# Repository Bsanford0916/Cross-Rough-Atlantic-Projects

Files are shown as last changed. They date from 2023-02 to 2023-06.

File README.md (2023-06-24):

**Welcome**

Hi there and welcome! Thanks alot for checking out Mjölnir - We've been so excited to share this with you, that we simply could'nt wait any longer. This blaster is for the community, by the community. 

This is the finished blaster after about 8 months of work from alot of cool people, but we are hobby-nerf folk, not professionals (Try it out at your own risk).

This is a personal blaster for you and we want you to mod it. There is however a few legal things; The code is a mix of Airzone's free code. This means you are not allowed to sell it. The same goes for the design, which is mainly because we dont want to get kicked off github later on.. 😛 

But you are free to use it as you please to mod etc. You can print all the blasters you want for friends and family for the cost of filament and hugs.

if you have any questions, feel free to reach out to us via discord (https://discord.gg/Edy7qAxdAY) or facebook. 

Kind regards,

Ben, Thor and the rest of the C.R.A.P team

(Cross Rough Atlantic Projects)

**Licensing and Production**
Cross-Rough-Atlantic-Projects are all licensed under CC-BY-SA-NC https://creativecommons.org/licenses/by-nc-sa/4.0/

Shameless donation link:
https://www.buymeacoffee.com/projectmjolnir

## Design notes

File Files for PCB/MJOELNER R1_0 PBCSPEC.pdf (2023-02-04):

PCB SPECIFICATION DOCUMENT

PROJECT NAME / # | MJOELNER
PROJECT AUTHOR | TLH
PCB REVISION | 1.0
PCB BASE MATERIAL | FR-4, IPC-4101/21, Tg>110
PCB STACKUP | 4 layer: 4001: Standard 1.6mm 1oz (FR4)
PCB THICKNESS | 1.6 mm
PCB SIZE (mmXmm) | 66 X 30
Number of copper layers | 4
Copper thickness outer layers µm | 35
Copper thickness inner layers µm | 35
Surface finish | ENIG Gold (Ni/Au)
Solder mask | GREEN
Notation | WHITE

Gerber File extensions

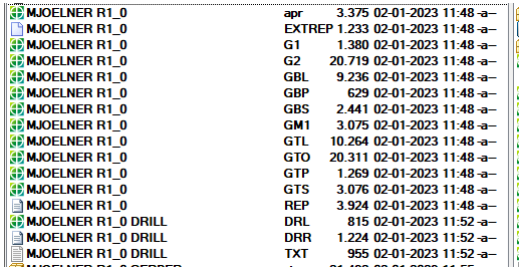
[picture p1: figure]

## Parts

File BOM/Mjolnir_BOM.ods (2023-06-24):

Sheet: Mjolnir
Mjölnir Base Components
Project files on Github | https://github.com/Bsanford0916/Cross-Rough-Atlantic-Projects
Item | Quantity | Link | Notes
Hardware
M3 screw 6mm (Button Head) | 8 | https://a.co/d/f6d6F2C
M3 screw 8mm (Button Head) | 2 | See options for sizes in above link.
M3 screw 10mm (Button Head) | 7 | See options for sizes in above link.
M2 screw 16mm (Button Head) | 4 | https://a.co/d/7gcIDZh
M2 screw 18mm (Button Head) | 1 | See options for sizes in above link.
Heat Insert (M3x3mm Lengthx5mm OD) | 17 | Https://a.co/d/2s1DLBN
Ballpen spring (mag release) | 1
5mmx2mm Magnet (Battery Lid) | 2
Electronics
Iflight Xing2 1404 4600kV | 2 | Https://a.co/d/bhoQbUt
Blheli_32 35A ESC (20A will work) | 1
Arduino Nano (Atmega328) | 1
Solenoid OOD Neutron | 1 | https://outofdarts.com/products/high-rate-of-fire-compact-solenoid
Rotary Encoder (with push switch) | 1 |  | KY-040 Without board, also in PCB BOM
0.96in OLED I2C (SSD 1306) | 1 | https://a.co/d/a85g2Zs
MicroSwitch 10A | 1 | https://outofdarts.com/products/10a-microswitch-cherry-db2-with-lever | Also in PCB BOM
MicroSwitch 1A | 1 | https://outofdarts.com/products/micro-switch-1a-for-mosfet-builds
Lipo 3s | 1 |  | 650mAh 75c 3s confirmed
22AWG wire | N/A
28AWG Wire | N/A
XT30 set | 1

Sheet: Mjolnir XL
Mjölnir XL Base Components
Project files on Github | https://github.com/Bsanford0916/Cross-Rough-Atlantic-Projects
Item | Quantity | Link | Notes
Hardware
Electronics

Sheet: Mjolnir Carbine
Mjölnir Carbine Base Components
Project files on Github | https://github.com/Bsanford0916/Cross-Rough-Atlantic-Projects
Item | Quantity | Link | Notes
Hardware
Electronics

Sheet: PCB Electronics
Mjölnir PCB Electronics Components
Project files on Github | https://github.com/Bsanford0916/Cross-Rough-Atlantic-Projects
Item | Quantity | Link | Notes
PCB
Capacitor 25v, 47uF | 1 | https://www.mouser.com/ProjectManager/ProjectDetail.aspx?AccessID=42ba671b8e | All in one Order BOM
Ceramic Capacitor 16v, 10uF | 2 |  | MLCC X7R 1206
Zener Diode 5v1 (BZT52C5V1) | 1 |  | SOD-123
Diode (VS-10MQ040-M3/5AT) | 2 |  | Do-214AC (SMA)
Voltage Regulator (UA7805M05CDCY) | 1 |  | SOT223-S
P-channel Mosfet (IPD30N10S3L34ATMA1) | 1 |  | Dpak (TO-252)
47k 1% 0.125W Resistor | 1 |  | R0805
10k 1% 0.125W Resistor | 2 |  | R0805
1k 1% 0.125W Resistor | 1 |  | R0805
2pin Header, 100mil | 2
4pin Header, 100mil | 1
5pin Header, 100mil | 1

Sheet: Alternate Parts
Mjölnir Alternate Components
Project files on Github | https://github.com/Bsanford0916/Cross-Rough-Atlantic-Projects
Item | Quantity | Link | Notes
Micro Dual BEC Board, 7-21V to 5V/12V ADJ | 1 | Https://a.co/d/8TOD3Te | Alternate Component
Isolated Mosfet Relay Board 30V 161A | 1 | Https://a.co/d/1EoDc6Q | LR7843
Solenoid 12V 2.5A (FJ-Z05 or OOD Neutron) | 1 | FJ-Z05 Solenoid Link https://a.co/d/eShqyR8 | Link says JF-Z05, but is the FJ-Z05 solenoid

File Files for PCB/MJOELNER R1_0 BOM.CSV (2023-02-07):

Comment | Pattern | Quantity | Components
NOT MOUNTED | RAD �7 X 2.54 | 1 | C3 | 47 �F/ 25 V
10k 1% .125w 0805 | R0805 | 1 | R2 | Resistor
10k 1% 0.125W 0805 | R0805 | 1 | R4 | Resistor
1k 1% 0.125W 0805 | R0805 | 1 | R3 | Resistor
47k 1% 0.125W 0805 | R0805 | 1 | R1 | Resistor
NOT MOUNTED |  | 1 | IC1 | ARDUINO NANO CONTROLLER
BZT52C5V1 | SOD-123 | 1 | D3 | ZENER 5V1
NOT MOUNTED | TLH ESC | 2 | J1, J4 | ESC CONNECT
NOT MOUNTED | FIDUCIAL | 2 | FIDUCIAL 1, FIDUCIAL 2
NOT MOUNTED | TLH 2PIN 100MIL | 2 | J8, J9 | Header 2 PIN 100 MIL
NOT MOUNTED | TLH 2PIN 100MIL | 1 | J5 | Header, 2-PIN 100 MIL
NOT MOUNTED | TLH 4PIN 100MIL | 1 | J7 | Header, 4-PIN 100 MIL
NOT MOUNTED | TLH 5PIN 100MIL | 1 | J6 | Header, 5-PIN 100 MIL
IPD30N10S3L34ATMA1 | TLH DPAK | 1 | Q1 | RS 671-0788
MLCC X7R 1206 | C1206 | 2 | C1, C2 | RS# 802-9961
NOT MOUNTED | TLH PWR IN | 1 | J2 | PWR IN HEADER
NOT MOUNTED | TLH PWR IN | 1 | J3 | SOLENOID CONNECT
UA7805M05CDCY | SOT223-S | 1 | IC2 | TEXAS
VS-10MQ040-M3/5AT | SMA | 2 | D1, D2 | Default Diode

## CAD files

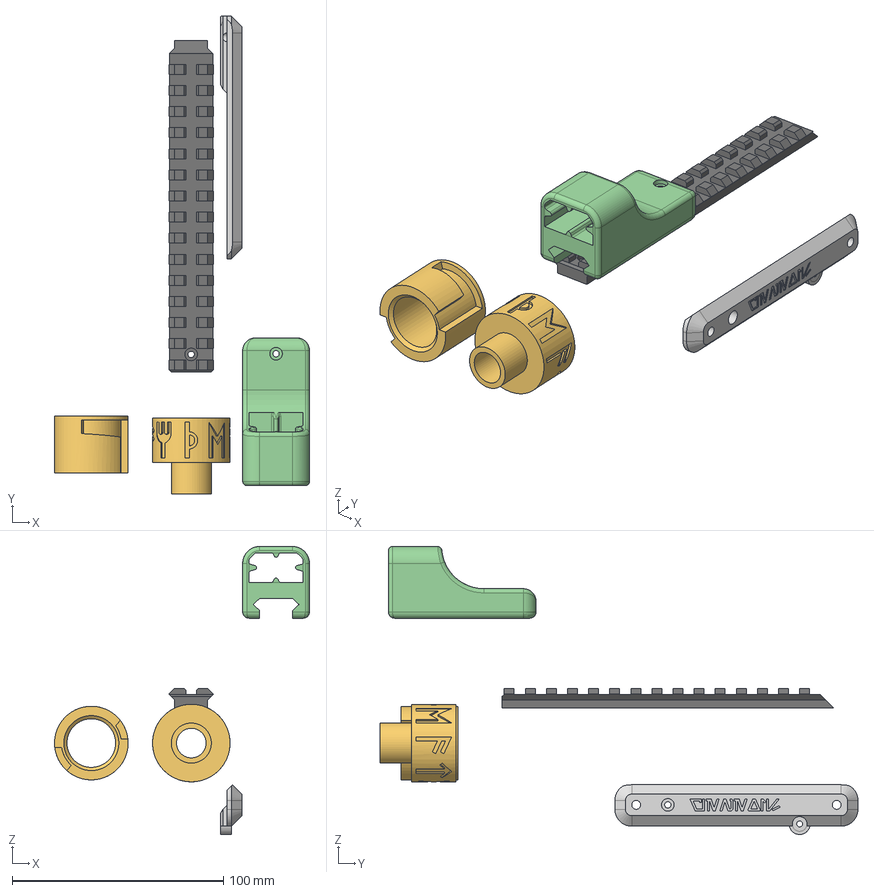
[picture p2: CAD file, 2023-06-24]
Files for 3d printing/Additional tacticool stuff/Assesories_V.2.4.6.step
120.8 x 226.5 x 136.5 mm
Fidlock Mount
Muzzle Threaded T238 Tracer - Works
Assesories_1
Muzzle N-Strike Adapter Not Tested

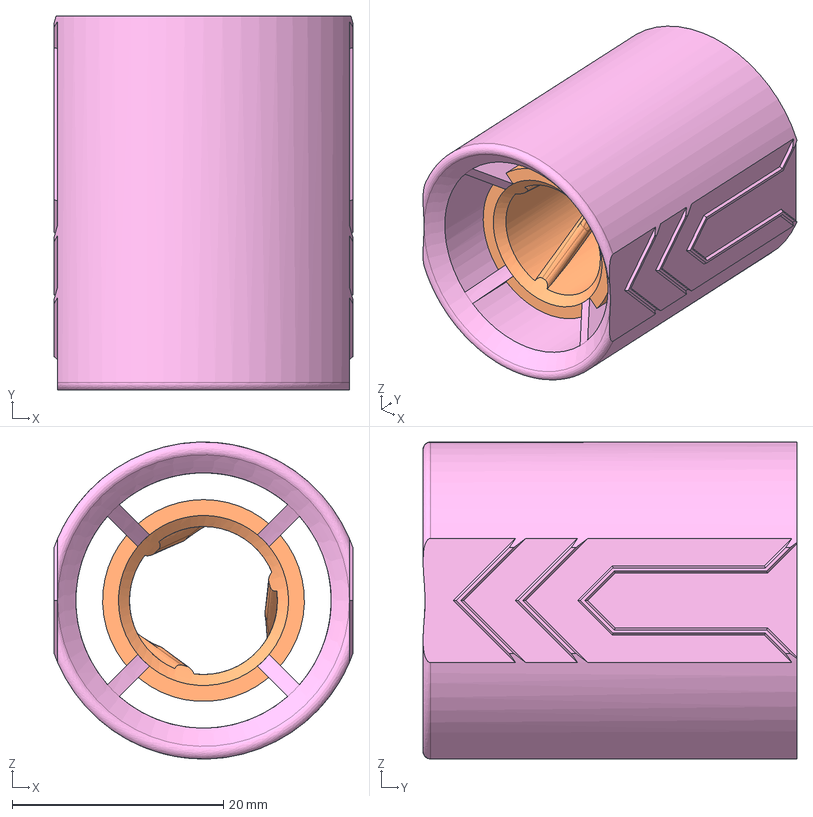
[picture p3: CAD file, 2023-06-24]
Files for 3d printing/Additional tacticool stuff/Not tested yet/PCAR_Muzzle-seperated.step
28.3 x 35.4 x 30.0 mm

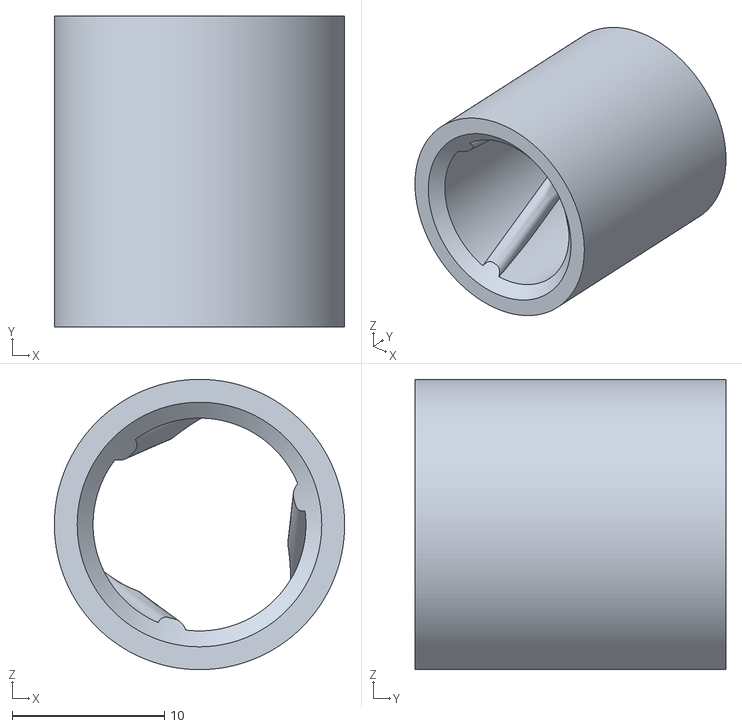
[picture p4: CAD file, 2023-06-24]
Files for 3d printing/Additional tacticool stuff/Not tested yet/Muzzle-PCAR.stl
19.1 x 20.5 x 19.1

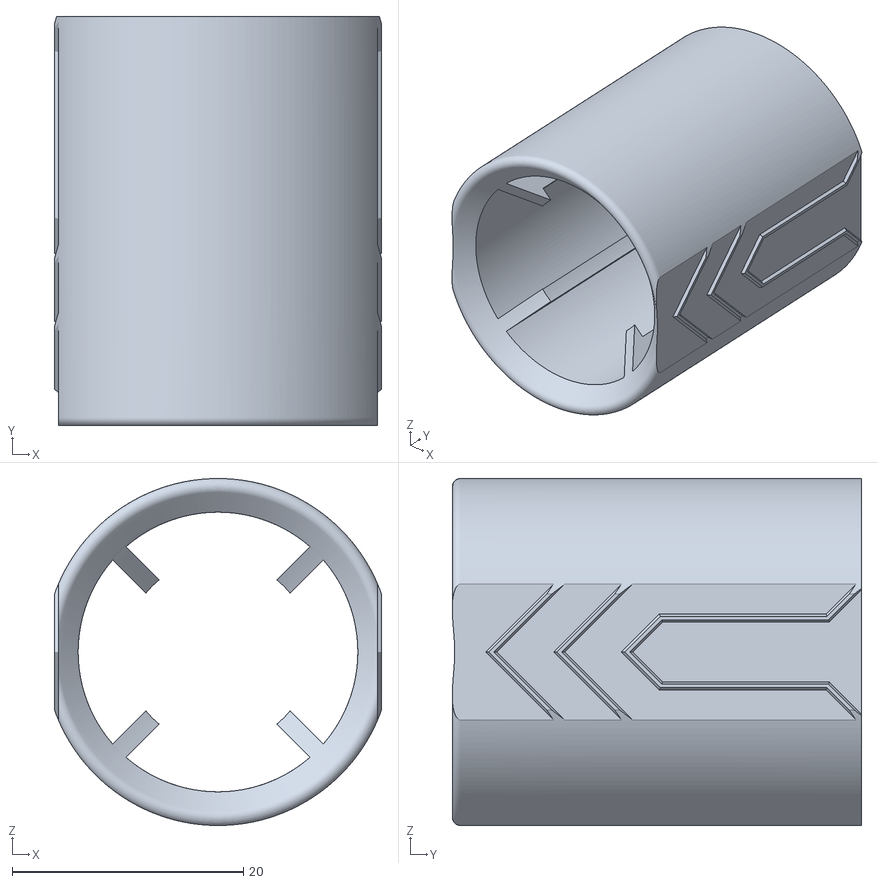
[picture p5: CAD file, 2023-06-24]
Files for 3d printing/Additional tacticool stuff/Not tested yet/Muzzle-Outer.stl
28.3 x 35.4 x 30.0

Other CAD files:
Files for 3d printing/Additional tacticool stuff/Not tested yet/PCAR_Muzzle-seperated.stl

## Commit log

2023-01-04 Updated wheels to correct awesome ones
2023-01-18 Update 1.14
    - Updated magwell to fit mag switch
    - Made MagSwitch
    - Updated Top to press-fit 0.96 OLED
    - Updated Motor mount to fit rotary encoder KY-040
    - Moved Solenoid back abit
    - Edited top to match new solenoid position
    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
2023-02-04 PCB, v2.90 step, Full code
    [MJOELNER R1_0 BOM.CSV, MJOELNER R1_0 PICKPLACE.csv]
2023-02-07 Updated PCB
    [MJOELNER R1_0 BOM.CSV, MJOELNER R1_0 PICKPLACE.csv]
2023-02-11 Mjolnir stl, updated code
    [Battery Lid.stl, FJ-Z05 Pusher.stl, Mag release.stl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]
2023-06-24 V1 release
    [Assesories_V.2.4.6.step, Battery Lid.stl, FJ-Z05 Pusher.stl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]
